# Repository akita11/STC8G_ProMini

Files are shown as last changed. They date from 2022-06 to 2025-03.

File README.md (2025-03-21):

# ST8G_ProMini

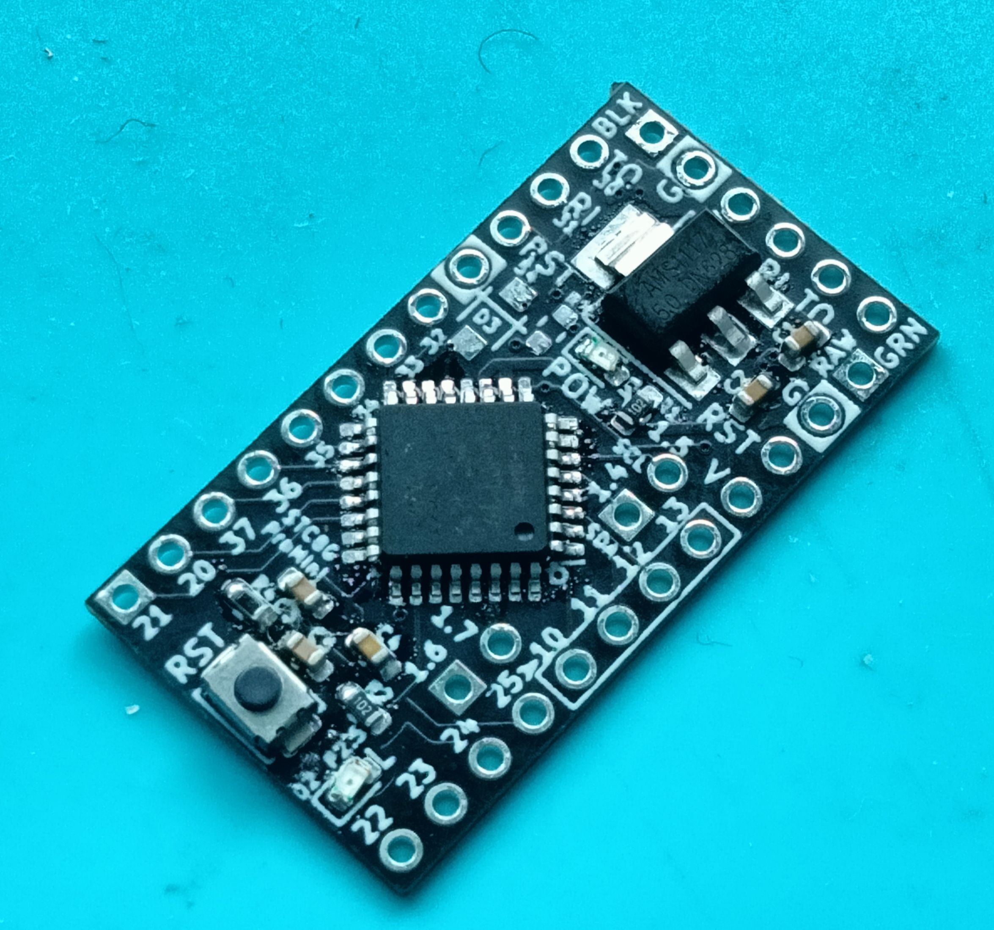
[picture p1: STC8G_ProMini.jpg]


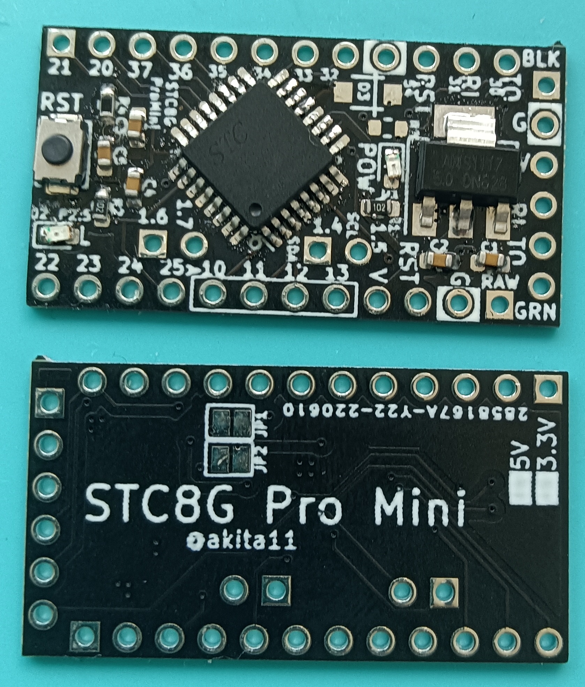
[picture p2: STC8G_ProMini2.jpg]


中国[STCmicro(宏晶科技)](https://www.stcmicro.com/)の8ビットマイコンSTC8G2K322を使った、Arduino Pro Mini型のマイコンボードです。
主な特徴は以下のとおりです。

- Arduino Pro Mini型（プログラム書き込みは、FTDI-Basicまたはその互換のUSB-シリアル変換器が必要です→[例](https://www.switch-science.com/catalog/1032/)）
- 電源電圧5V
- 全ピンアナログ入力・PWM出力可能
- RAM=2KB, フラッシュ=32KB
- 通信機能: UARTx4、SPI、I2C

またArduino Pro Miniとは、以下のような違いがあります。
- 現時点ではArduinoIDEでのプログラム開発環境はありませんが、[それを実現する進行中のプロジェクト](https://github.com/akita11/nulllab_stc51duino)があります。
- RAW端子に、外部電源から+7V以上を供給可能で、ボード上のレギュレータで+5Vを生成します。

## ピン配置

ボード上のArduino Pro Miniのピン位置とSTC8G2K32のピン名称との対応は以下の通りです。

- D0 - D7 : P3.0 - P3.7
- D8 - D13 : P2.0 - P2.5
- A0 - A7 : P1.0 - P1.7

基板上の"LED"（オレンジ）はP2.5（D13の位置）で駆動できます。詳細は[回路図](https://github.com/akita11/STC8G_ProMini/blob/main/STC8G_ProMini_sch.pdf)を参照してください。

## プログラムのコンパイルと書き込み

現時点では、ArduinoIDEは使えませんので、プログラムのコンパイルと書き込みは、それぞれ別のツールを使うことになります。（[使い方のメモ](https://note.com/akita11/n/n41316faaaf19)も参照してください）

### プログラムのコンパイル

STC8Gマイコンは8051コアですので、フリーから商用のものまでいろいろなコンパイラがあります。動作確認をしたものを照会しておきます。またsourceフォルダ以下に、プログラム例があります（ビルド方法は、以下のKsylitoliの手順を参照）。

- SDCC（オープンソースなコンパイラ）。Macでの使用例は[Ksylitoli](https://github.com/creeper0723/Ksylitoli)の説明がわかりやすいです。またWindows用やLinux用もあります（SDCC公式サイトからダウンロードできる）
- [FwLib_STC8](https://note.com/akita11/n/n41316faaaf19)。簡易ライブラリですが、レジスタ定義ファイルを流用できます。

### プログラムの書き込み

[STCmicro](https://www.stcmicro.com/rjxz.html)のWebページから、書き込みツールSTC-ISPをダウロードします。

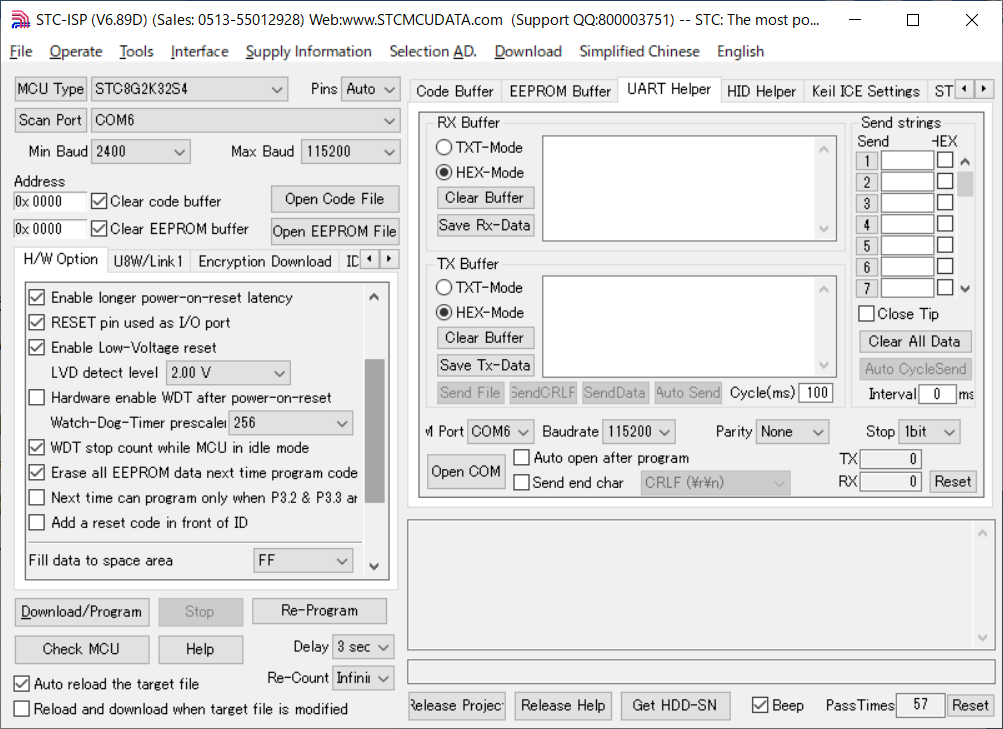
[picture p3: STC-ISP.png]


USB-シリアル変換器をPCに接続し（初回時は、ここではまだSTC8G_ProMiniは接続しない）、STC-ISPを起動し、以下の設定をします。
- "MCU Type"で、**STC8G2K32S4**を選択
- "Scan Port"には、接続しているUSB-シリアル変換器のCOMポートを選択
- "Open Code File"で、コンパイルで得られた*.binを指定
- "H/W Option"で、**RESET pin used as I/O port**のチェックを**はずす**（これのチェックが入っていると、RSTピンが通常のI/Oピン(P5.4)となり、リセットSWやFTDI-Basicからのリセットがかけられません。それでもよいのでP5.4を通常のI/Oとして使用する場合はチェックを入れる）
- 内部フラッシュ内のキャリブレーション情報を使う場合は、**Add a reset code in front of ID**をチェックする

設定が済んだら、"Download/Program"ボタンを押します。

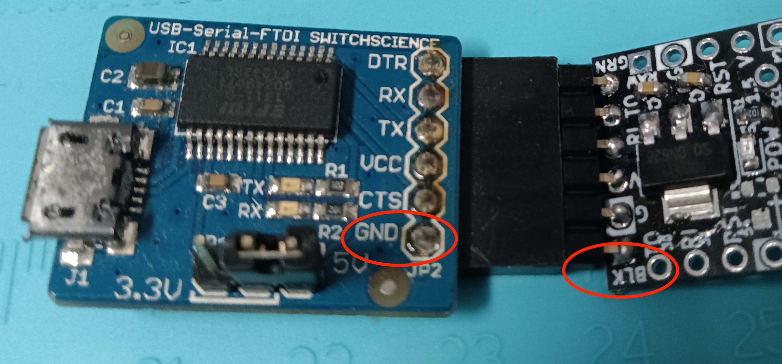
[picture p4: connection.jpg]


初回時のみ、その後で、FTDI-BasicにSTC8G_ProMiniを、向きに注意して接続します。（FTDI-BasicのGNDと、STC8G_ProMiniの"BLK"が揃う向き）すぐに書き込みが始まります。終了したらRSTスイッチでリセットするとプログラムが実行されます。
STC-ISPの設定で、RSTピンを使うように指定してあれば、2回目以降は、FTDI-Basicに接続したままで、Download/Promramを押すだけで自動でリセットがかかり、書き込みができます。

## Author

Junichi Akita (@akita11) / akita@ifdl.jp

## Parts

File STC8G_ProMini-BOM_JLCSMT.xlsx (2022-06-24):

Comment | Designator | Footprint | JLCPCB Part #（optional）
10uF | C2,C4 | C0603 | C14663
0.1uF | C3,C1,C5 | C0603 | C96446
LED(G) | D1 | D0603 | C2289
LED(Y) | D2 | D0603 | C165981
STC8G2K32 | U2 | QFP32 | C915670
10k | R4 | R0603 | C25804
1.1k | R2,R1 | R0603 | C22764
LM1117 | U1 | SOT223-3 | C347223
PushSW | SW1 | SKRK | C720477

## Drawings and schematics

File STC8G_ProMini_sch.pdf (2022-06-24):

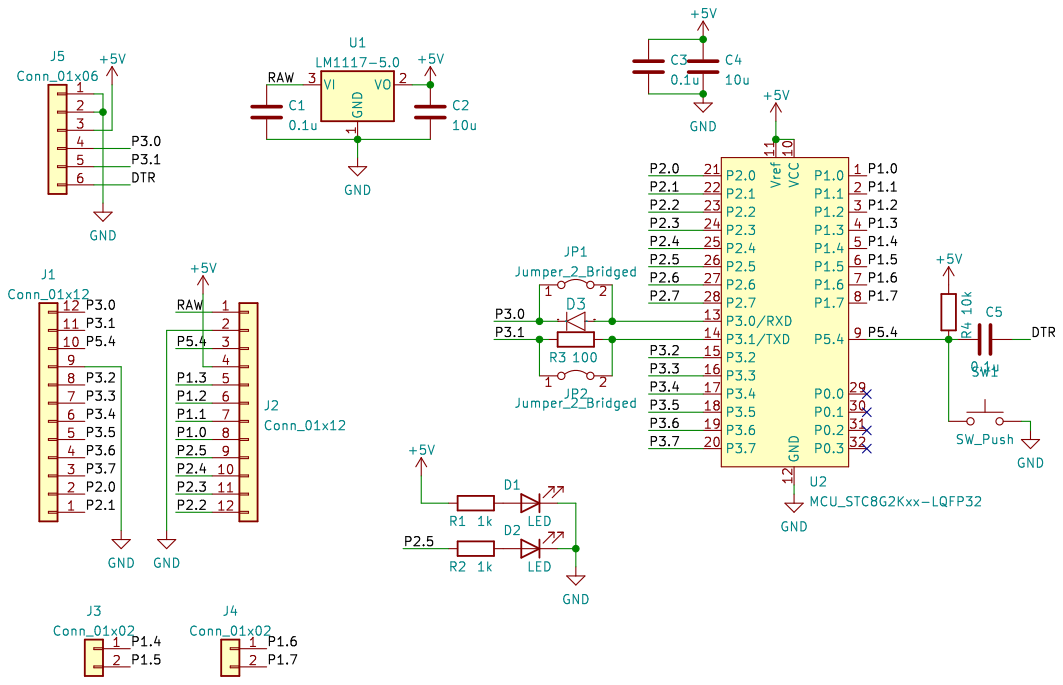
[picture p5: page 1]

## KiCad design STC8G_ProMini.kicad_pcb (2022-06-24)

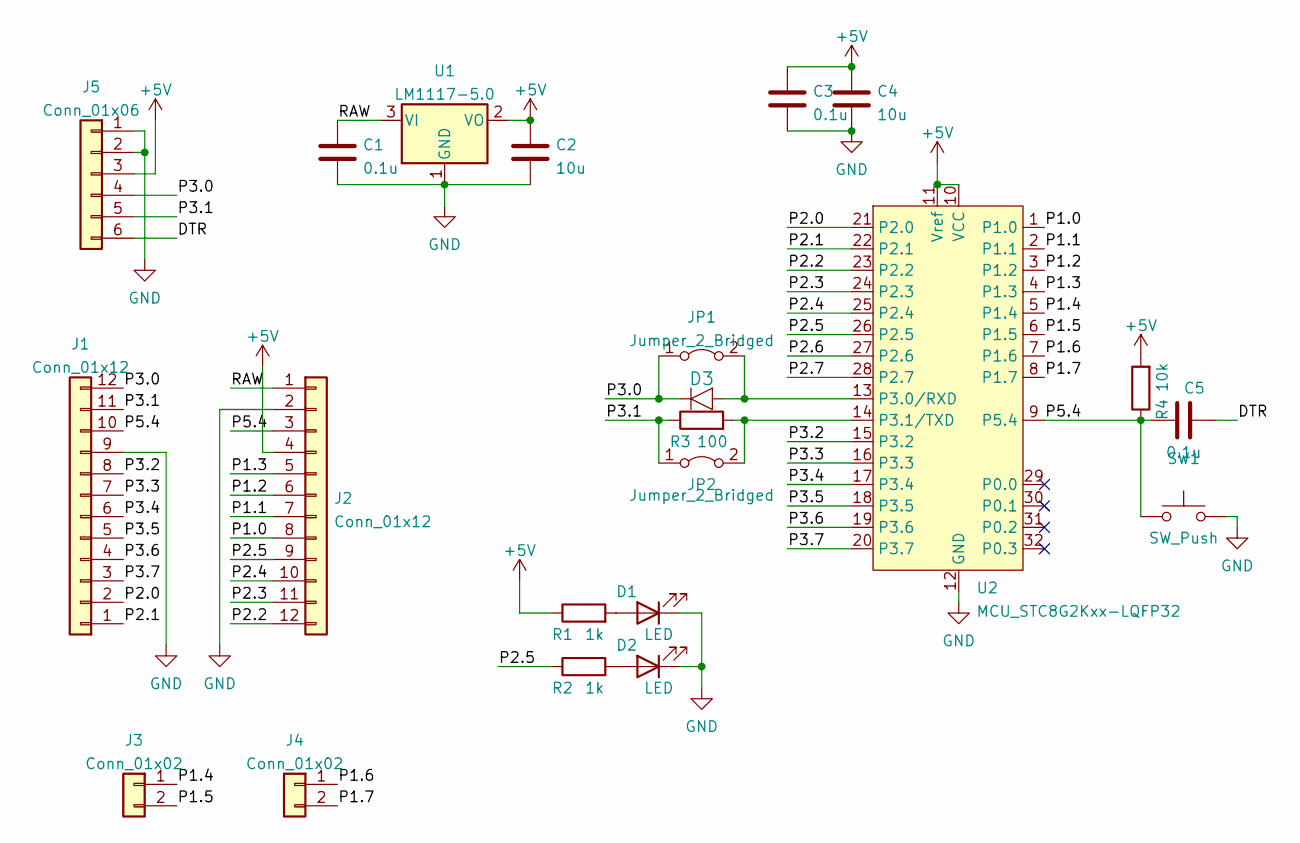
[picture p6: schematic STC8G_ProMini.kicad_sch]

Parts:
C1, C3, C5: 0.1u; C_0603_1608Metric
C2, C4: 10u; C_0603_1608Metric
D1, D2: LED; LED_0603_1608Metric
D3: DIODE; D_SOD123FL
J1, J2: Conn_01x12; PinSocket_1x12_P2.54mm_Vertical
J3, J4: Conn_01x02; PinSocket_1x02_P2.54mm_Vertical
J5: Conn_01x06; PinSocket_1x06_P2.54mm_Vertical
JP1, JP2: Jumper_2_Bridged; SolderJumper-2_P1.3mm_Bridged_Pad1.0x1.5mm
R1, R2: 1k; R_0603_1608Metric
R3: 100; R_0603_1608Metric
R4: 10k; R_0603_1608Metric
SW1: SW_Push; SW_Push_SPST_NO_Alps_SKRK
U1: LM1117-5.0; SOT-223-3_TabPin2
U2: MCU_STC8G2Kxx-LQFP32; LQFP-32_7x7mm_P0.8mm

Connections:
+5V: C2.1, C3.1, C4.1, J2.4, J5.3, R1.1, R4.2, U1.2 (VO), U2.10 (VCC), U2.11 (Vref)
/DTR: C5.2, J5.6
/P1.0: J2.8, U2.1 (P1.0)
/P1.1: J2.7, U2.2 (P1.1)
/P1.2: J2.6, U2.3 (P1.2)
/P1.3: J2.5, U2.4 (P1.3)
/P1.4: J3.1, U2.5 (P1.4)
/P1.5: J3.2, U2.6 (P1.5)
/P1.6: J4.1, U2.7 (P1.6)
/P1.7: J4.2, U2.8 (P1.7)
/P2.0: J1.2, U2.21 (P2.0)
/P2.1: J1.1, U2.22 (P2.1)
/P2.2: J2.12, U2.23 (P2.2)
/P2.3: J2.11, U2.24 (P2.3)
/P2.4: J2.10, U2.25 (P2.4)
/P2.5: J2.9, R2.1, U2.26 (P2.5)
/P2.6: U2.27 (P2.6)
/P2.7: U2.28 (P2.7)
/P3.0: D3.K, J1.12, J5.4, JP1.1 (A)
/P3.1: J1.11, J5.5, JP2.1 (A), R3.1
/P3.2: J1.8, U2.15 (P3.2)
/P3.3: J1.7, U2.16 (P3.3)
/P3.4: J1.6, U2.17 (P3.4)
/P3.5: J1.5, U2.18 (P3.5)
/P3.6: J1.4, U2.19 (P3.6)
/P3.7: J1.3, U2.20 (P3.7)
/P5.4: C5.1, J1.10, J2.3, R4.1, SW1.1, U2.9 (P5.4)
/RAW: C1.1, J2.1, U1.3 (VI)
GND: C1.2, C2.2, C3.2, C4.2, D1.1 (K), D2.1 (K), J1.9, J2.2, J5.1, J5.2, SW1.2, U1.1 (GND), U2.12 (GND)
unnamed: D1.2 (A), R1.2
unnamed: D2.2 (A), R2.2
unnamed: D3.A, JP1.2 (B), U2.13 (P3.0/RXD)
unnamed: JP2.2 (B), R3.2, U2.14 (P3.1/TXD)

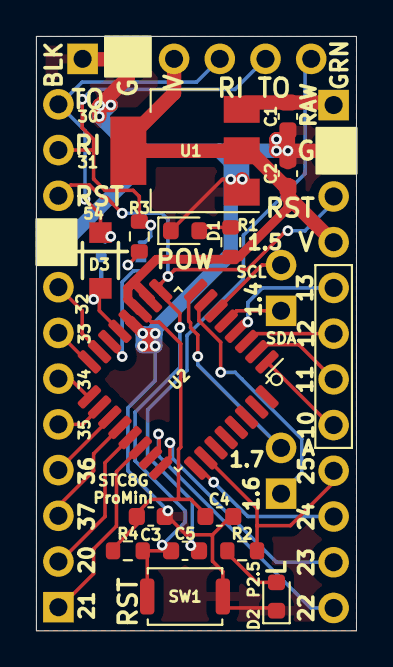
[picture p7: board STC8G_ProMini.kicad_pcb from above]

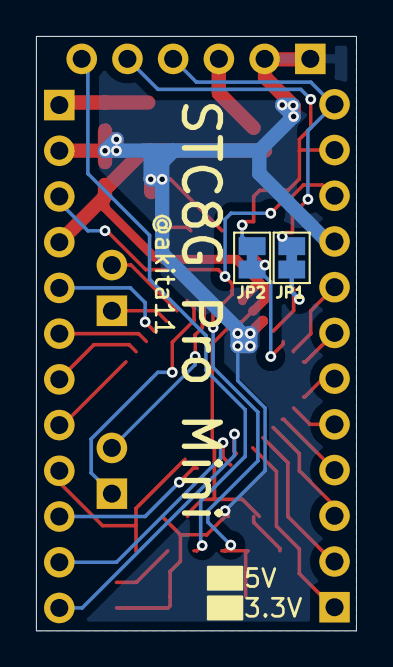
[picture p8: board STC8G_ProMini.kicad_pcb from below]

Board: 2 copper layers, 17.8 x 33.0 mm, 22 parts (2 on the bottom side), 31 nets.
